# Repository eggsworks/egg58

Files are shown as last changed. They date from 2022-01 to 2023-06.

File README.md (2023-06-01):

# egg58

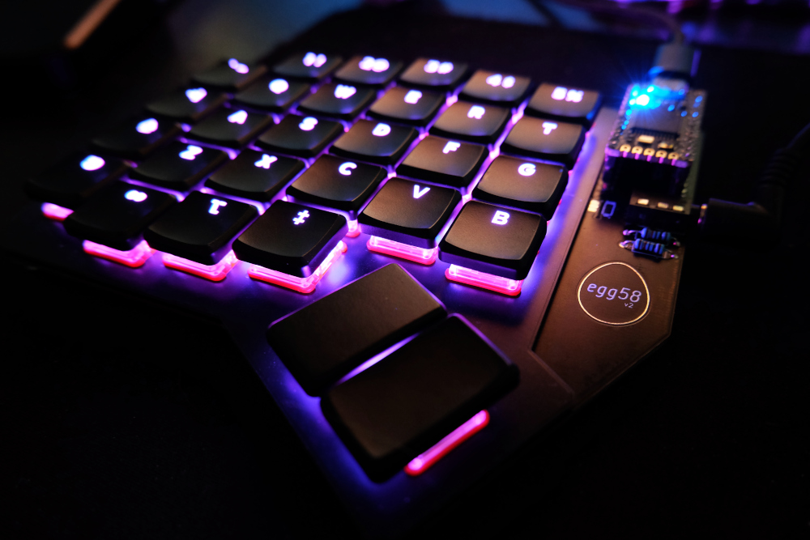
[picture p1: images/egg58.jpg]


The egg58 is a staggered-column, split, low-profile keyboard with 58 keys and per-key RGB. The PCB is reversible (i.e. the same part is used for both hands). This repository contains its design files.

## Layout

The egg58 was designed to remain fairly close in layout to an ANSI 60% keyboard, but with a reduced number of keys and
minimal thumb clusters.

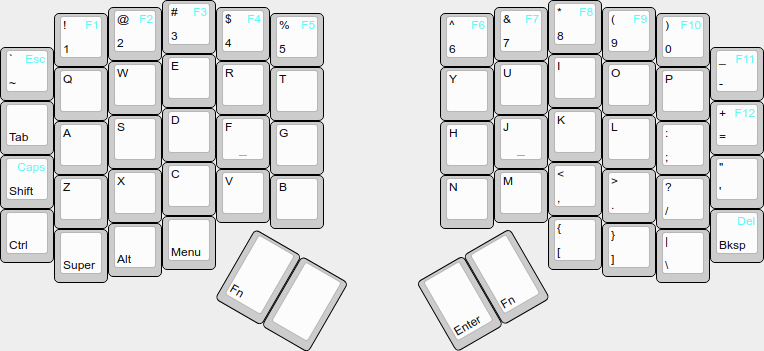
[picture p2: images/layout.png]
layout


This is a suggested layout, but obviously it is customizable.

## Original variant

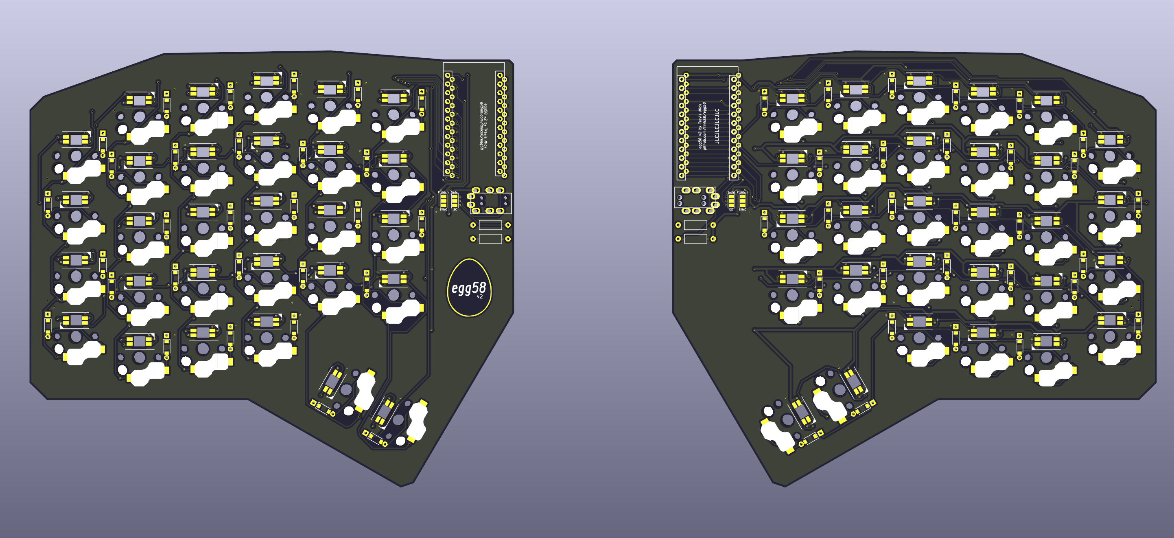
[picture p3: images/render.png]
render


The original (wired) keyboard design files can be found in directory [egg58v2](egg58v2).

### Materials

- 2x PCB (from this repo)
- 2x switchplate (from this repo)
- 2x Pro Micro or Elite-C
- 2x 4.7K through hole resistors (for I2C option)
- 2x 3.5mm TRRS jack (PJ-320A)
- 58 Choc sockets
- 58 Choc switches (Choc V1 only)
- 58 diodes (1N4148 or similar, throughhole or SOD123)
- 58 SK6812 Mini-E LEDs
- 1x TRRS cable

### Build instructions

On the back of each board:

- Install LEDs such that the notched corner aligns with the indicator on the silkscreen.
  - Be aware that the orientation of the LEDs changes each row.
- Install diodes, such that the cathode (the side with the line) points toward the square holes (upward). 
  - If using through-hole diodes with the FR4 switchplate, ensure that the leads are trimmed very short on the front, otherwise they may scratch through the switchplate solder mask and short out.
- Install sockets.
- If I2C is being used, install the two resistors beneath the location for the TRRS. (They can be placed on the front instead if desired.)
  - Recommended to use either 2x 4.7K on a single hand, or 4x 10K on both hands.
  - The values are fairly flexible, as long as the total resistance on each line is between 2.2K-10K.
- Solder the two jumpers to select serial/I2C and Elite-C/Pro Micro.
  - The EliteC/ProMicro jumper selects the position of the VBUS/RAW pin, to supply 5v to the LEDs and across the TRRS cable. On the Elite-C, the RAW pin is replaced with an extra I/O pin (B0) and an extra VBUS pin is added above it. Select EliteC in this case, or ProMicro for all others.
  - The Serial/I2C jumper selects which data pin is attached to the TRRS jack. The firmware uses I2C by default, but select Serial if you have customized it.
  - Each jumper should have one "outer" pad soldered to the inner pad. See [Issue #4](https://github.com/eggsworks/egg58/issues/4) for further explanation and a diagram.

On the front:

- Install TRRS.
- Install MCU (preferably in a socket).

Mount the switchplate to the PCB with 5x M2 screws. Nylon screws are recommended. A spacer is recommended between the two layers. Finally, install switches in the sockets.

### Firmware

My [fork of QMK](https://github.com/tmick0/qmk_firmware/tree/egg58/keyboards/egg58) contains default configuration and a keymap for the board.

The configuration will need to be changed if using soft serial instead of I2C, or if your microcontrollers do not use the DFU bootloader.

### Changelog

#### Revision 2.1 - 2023-04-01

- Add support for VBUS from Elite-C

#### Revision 2.0 - 2022-03-04

- Original Chocs are used rather than Choc v2
- There is an option to use soft serial instead of I2C for the bridge transport
- The Elite-C microcontroller is now supported in addition to the Pro Micro
- The LEDs are now north-facing (since that is more suitable for the only shine-through caps for Choc currently available)
- The thumb cluster is now designed for 2x 1.5u instead of one 1.5u and one 2u key
- Keys now use Choc spacing instead of MX (be aware of this when purchasing keycaps)

## Wireless variant

A simplified version designed to be used with ZMK is available in the [egg58bt](egg58bt) directory. This version has no RGB and uses BLE for both connectivity to the host and the split transport.

### Materials

- 2x PCB (from this repo)
- 2x switchplate (from this repo)
- 2x nice!nano microcontrollers
- 58 Choc sockets
- 58 Choc switches (Choc V1 only)
- 58 diodes (1N4148 or similar, throughhole or SOD123)

### Build instructions

Construction is the same as the original variant above, just skip the steps related to the split transport and LEDs.

### Firmware

ZMK support is available from my [zmk-config](https://github.com/tmick0/zmk-config) repo.

### Changelog

#### 2023-02-20

- Created wireless variant

## Accessories

A 3D-printable case compatible with both the original and wireless boards can be found in [egg58v2 case](egg58v2%20case). The case uses M2 threaded heat-set inserts to mount the board.

Minimal tenting stands in 15, 10, and 5 degree variants can be printed from the models in [egg58v2 tenting stands](egg58v2%20tenting%20stands). They also use M2 threaded inserts. The tenting stands are mutually exclusive with the full-bottom case.  Rubber bumpons should be applied to the bottom of the stands, and on the "outside" edge of the PCB where the stands do not attach.

A model for a wrist rest is also available in [egg58v2 wrist rest](egg58v2%20wrist%20rest).

## License

This repository is available under the terms of the [GPL, verison 3](LICENSE).

Some portions are derived from:

- [keyswitches.pretty](https://github.com/daprice/keyswitches.pretty) ([CC BY-SA 4.0](https://creativecommons.org/licenses/by-sa/4.0/))
- [Keebio-Parts.pretty](https://github.com/keebio/Keebio-Parts.pretty) ([MIT](https://github.com/keebio/Keebio-Parts.pretty/blob/master/LICENSE))
- [ProMicroKiCad](https://github.com/Biacco42/ProMicroKiCad) ([MIT](https://github.com/Biacco42/ProMicroKiCad/blob/master/LICENSE))
- [SofleKeyboard](https://github.com/josefadamcik/SofleKeyboard) ([MIT](https://github.com/josefadamcik/SofleKeyboard/blob/master/LICENSE))

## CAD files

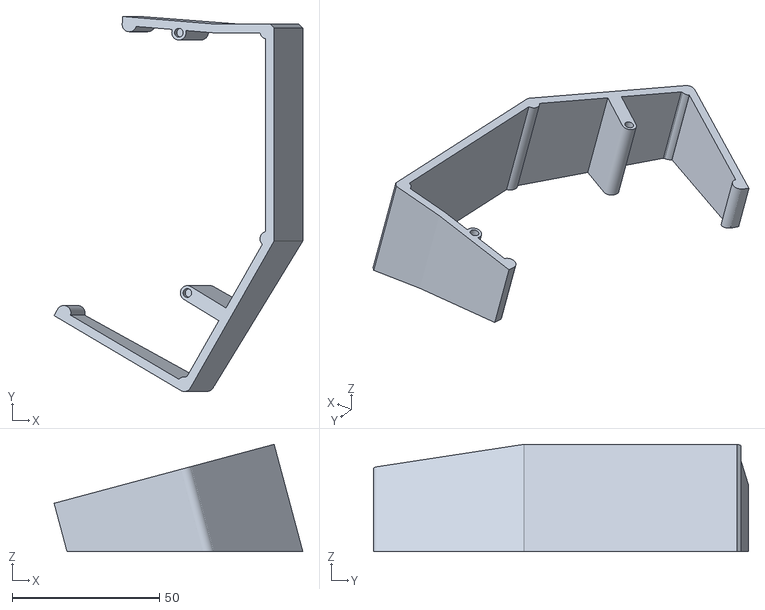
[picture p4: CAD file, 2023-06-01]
egg58v2 tenting stands/egg58 tenting - 15deg - left.stl
84.6 x 127.5 x 36.5

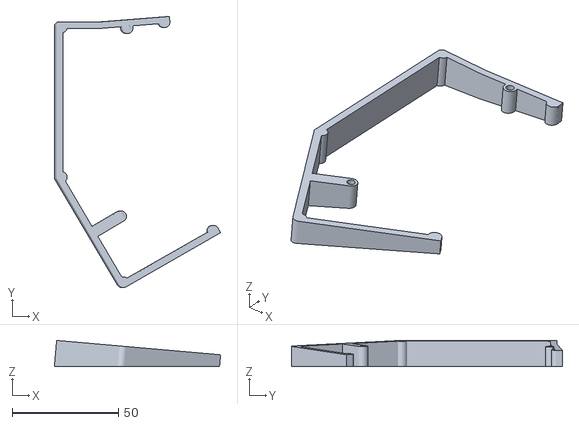
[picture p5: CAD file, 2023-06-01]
egg58v2 tenting stands/egg58 tenting - 5deg - right.stl
78.3 x 127.5 x 12.3

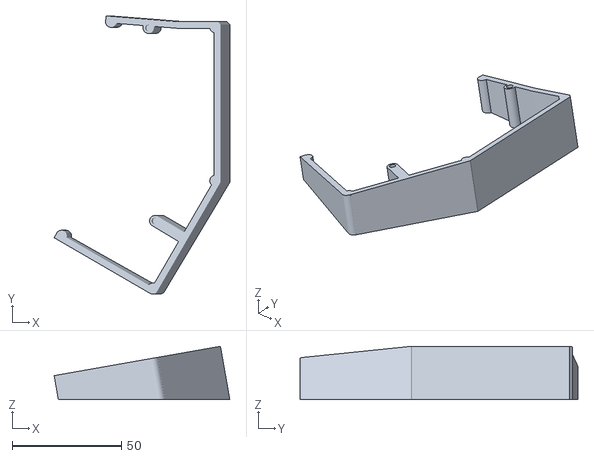
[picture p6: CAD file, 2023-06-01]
egg58v2 tenting stands/egg58 tenting - 10deg - left.stl
80.6 x 127.5 x 24.5

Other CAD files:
egg58v2 tenting stands/egg58 tenting - 15deg - right.stl
egg58v2 tenting stands/egg58 tenting - 5deg - left.stl
egg58v2 tenting stands/egg58 tenting - 10deg - right.stl

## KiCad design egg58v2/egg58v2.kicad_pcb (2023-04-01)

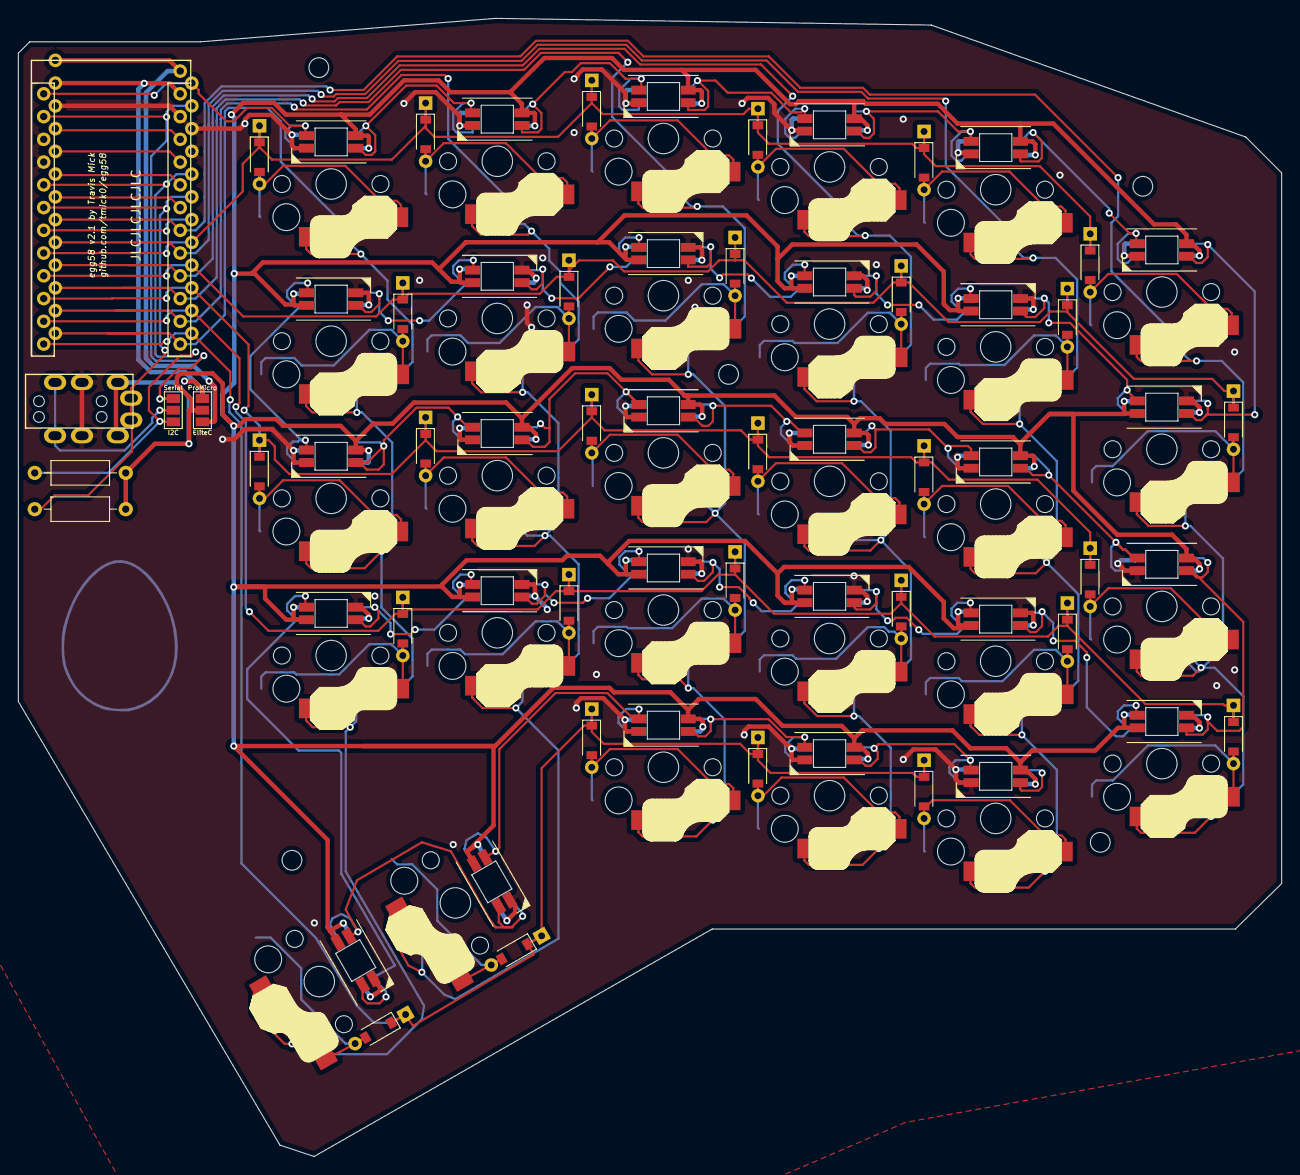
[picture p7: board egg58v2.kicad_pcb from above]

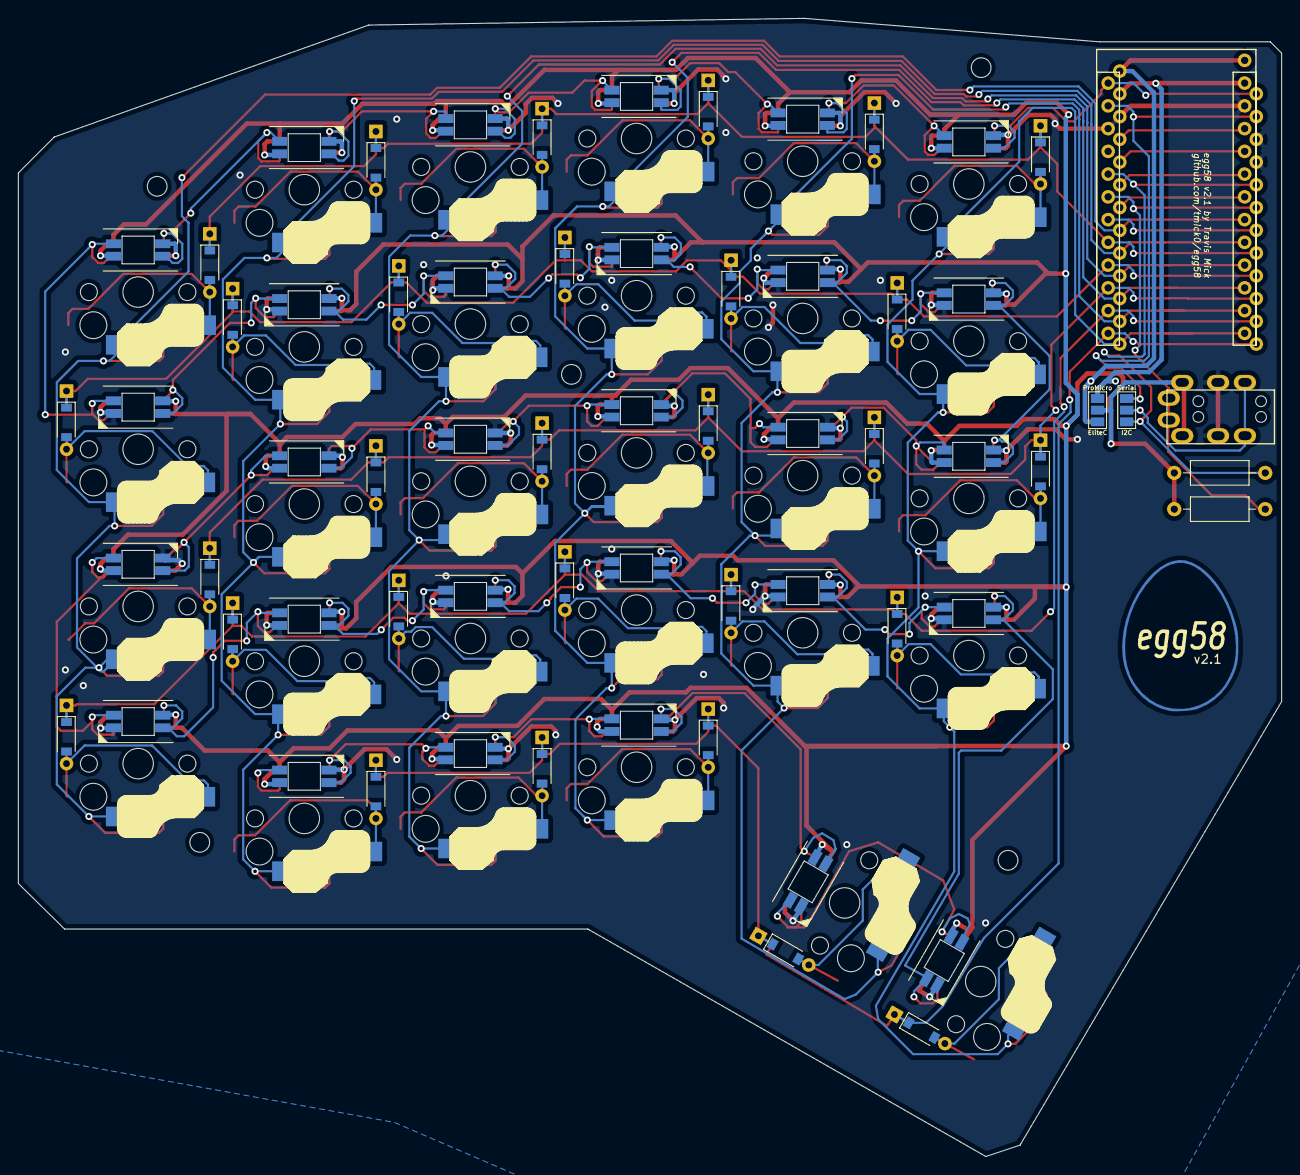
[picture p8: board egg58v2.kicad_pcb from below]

Board: 2 copper layers, 141.1 x 127.1 mm, 35 parts (16 on the bottom side), 48 nets.

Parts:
J1: AudioJack4; MJ-4PP-9
JP1, JP2: Jumper_NC_Dual; SolderJumper-3_P1.3mm_Open_Pad1.0x1.5mm_NumberLabels
R1, R2: 100k; R_Axial_DIN0207_L6.3mm_D2.5mm_P10.16mm_Horizontal
SW11, SW12, SW13, SW14, SW15, SW16, SW21, SW22, SW23, SW24, SW25, SW26, SW31, SW32, SW33, SW34, SW35, SW36, SW41, SW42, SW43, SW44, SW45, SW46, SW52, SW53, SW54, SW55, SW56: SW_PUSH_LED; Choc_Hotswap_SK6812MiniE
U1: Elite-C; ProMicro

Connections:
Col1: SW11.5, SW21.5, SW31.5, SW41.5, U1.18
Col2: SW12.5, SW22.5, SW32.5, SW42.5, SW52.5, U1.17
Col3: SW13.5, SW23.5, SW33.5, SW43.5, SW53.5, U1.16
Col4: SW14.5, SW24.5, SW34.5, SW44.5, SW54.5, U1.15
Col5: SW15.5, SW25.5, SW35.5, SW45.5, SW55.5, U1.14
Col6: SW16.5, SW26.5, SW36.5, SW46.5, SW56.5, U1.13
DATA: J1.3, JP2.2
GND: J1.2, SW11.3, SW12.3, SW13.3, SW14.3, SW15.3, SW16.3, SW21.3, SW22.3, SW23.3, SW24.3, SW25.3, SW26.3, SW31.3, SW32.3, SW33.3, SW34.3, SW35.3, SW36.3, SW41.3, SW42.3, SW43.3, SW44.3, SW45.3, SW46.3, SW52.3, SW53.3, SW54.3, SW55.3, SW56.3, U1.3, U1.4, U1.23
unnamed: SW11.2, SW21.4
unnamed: SW11.4, SW12.2
unnamed: SW12.4, SW13.2
unnamed: SW13.4, SW14.2
unnamed: SW14.4, SW15.2
unnamed: SW15.4, SW16.2
unnamed: SW21.2, SW22.4
unnamed: SW22.2, SW23.4
unnamed: SW23.2, SW24.4
unnamed: SW24.2, SW25.4
unnamed: SW25.2, SW26.4
unnamed: SW26.2, SW36.4
unnamed: SW31.2, SW41.4
unnamed: SW31.4, SW32.2
unnamed: SW32.4, SW33.2
unnamed: SW33.4, SW34.2
unnamed: SW34.4, SW35.2
unnamed: SW35.4, SW36.2
unnamed: SW41.2, SW42.4
unnamed: SW42.2, SW43.4
unnamed: SW43.2, SW44.4
unnamed: SW44.2, SW45.4
unnamed: SW45.2, SW46.4
unnamed: SW46.2, SW56.4
unnamed: SW52.4, SW53.2
unnamed: SW53.4, SW54.2
unnamed: SW54.4, SW55.2
unnamed: SW55.4, SW56.2
RGB: SW16.4, U1.1
Row1: SW11.7, SW12.7, SW13.7, SW14.7, SW15.7, SW16.7, U1.8
Row2: SW21.7, SW22.7, SW23.7, SW24.7, SW25.7, SW26.7, U1.9
Row3: SW31.7, SW32.7, SW33.7, SW34.7, SW35.7, SW36.7, U1.10
Row4: SW41.7, SW42.7, SW43.7, SW44.7, SW45.7, SW46.7, U1.11
Row5: SW52.7, SW53.7, SW54.7, SW55.7, SW56.7, U1.12
SCL: J1.4, R2.2, U1.6
SDA: JP2.3, R1.2, U1.5
SERIAL: JP2.1, U1.2
VBUS: JP1.1, U1.24
VCC: J1.1, JP1.2, R1.1, R2.1, SW11.1, SW12.1, SW13.1, SW14.1, SW15.1, SW16.1, SW21.1, SW22.1, SW23.1, SW24.1, SW25.1, SW26.1, SW31.1, SW32.1, SW33.1, SW34.1, SW35.1, SW36.1, SW41.1, SW42.1, SW43.1, SW44.1, SW45.1, SW46.1, SW52.1, SW53.1, SW54.1, SW55.1, SW56.1
VREG: JP1.3, U1.25

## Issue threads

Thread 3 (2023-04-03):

Choc spacing

nanpuhaha, 2023-04-03:
Please make choc spacing version.

tmick0, 2023-04-03:
Hi @nanpuhaha, the current version is already nominally choc spacing (actual footprint 18.5x17.5mm). Do you mean you want tighter tolerances on this, or did you mean you want an MX version?

nanpuhaha, 2023-04-06:
As I know, choc spacing is [18 x 17mm](https://geekhack.org/index.php?topic=107487.0). I wonder why you decided to make it a bit larger.

tmick0, 2023-04-06:
When I was initially designing this, I found that actual spacing among choc boards seems to vary up to 1mm from the nominal 18x17. I chose the .5mm larger footprint as to give a full 1mm gap between keycaps. This helps me prevent typos since I have larger fingers, and it also turned out to the provide necessary space to route the traces... However I could probably make the 18x17 work in a version that only supports SMT diodes.

I have just started on a design for an SMT-only version anyway - so, I may as well try to reduce the spacing simultaneously. I'll let you know how it goes :)

Closed 2023-05-24.

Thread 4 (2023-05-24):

Question About jumpers

cj360, 2023-05-24:
So I have a pair of sea-micros another pro micro clone and the I2C resistors for a set of egg58.
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

Should I be adding a jumper like the red color or just solder the pads like cyan?

Closed 2023-06-14.

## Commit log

2022-01-26 update to choc switch spacing, add logo
    [egg58v2.kicad_pcb]
2022-01-26 footprint updates
    [egg58v2.kicad_pcb, egg58v2.sch]
2022-01-28 make LEDs north facing
    [egg58v2.kicad_pcb]
2022-01-28 add option for i2c back
    [egg58v2.kicad_pcb, egg58v2.sch]
2022-01-28 starting routing
    [egg58v2.kicad_pcb, egg58v2.sch]
2022-01-30 starting routing for matrix
    [egg58v2.kicad_pcb]
2022-01-31 routing fixes
    [egg58v2.kicad_pcb]
2022-02-19 underp footprints and route everything i guess
    [egg58v2.kicad_pcb]
2022-02-19 fix (most) vias through silks
    [egg58v2.kicad_pcb]
2022-03-04 Mounting holes
    [egg58v2.kicad_pcb]
2022-03-04 First draft of switchplate
    [egg58v2.kicad_pcb, egg58v2_switchplate.kicad_pcb]
2022-03-04 Final touches on switchplate
    [egg58v2_switchplate.kicad_pcb]
2023-01-10 Add wrist rest stl
2023-03-21 Add wireless egg58 (#2)
    [egg58v2.kicad_pcb, egg58v2.sch]
2023-04-01 Add support for VBUS from EliteC
    [egg58v2.kicad_pcb, egg58v2.sch]
2023-04-01 Update wrist rest STL, add case STL, update readme
2023-06-01 Update case, add tenting stands
    [egg58 tenting - 10deg - left.stl, egg58 tenting - 10deg - right.stl, egg58 tenting - 15deg - left.stl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]
